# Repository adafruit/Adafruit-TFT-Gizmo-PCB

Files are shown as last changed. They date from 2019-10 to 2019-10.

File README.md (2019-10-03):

## Adafruit Circuit Playground TFT Gizmo - Bolt-on Display + Audio Amplifier PCB

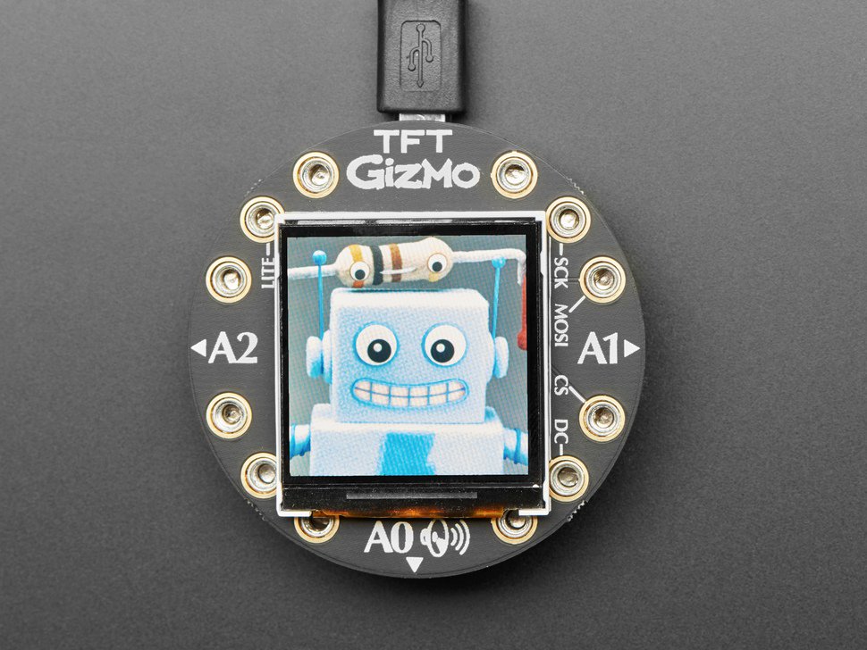
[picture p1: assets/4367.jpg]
<a href="http://www.adafruit.com/products/4367"><br/>
Click here to purchase one from the Adafruit shop</a>

PCB files for the Adafruit Circuit Playground TFT Gizmo - Bolt-on Display + Audio Amplifier. 

Format is EagleCAD schematic and board layout
* https://www.adafruit.com/product/4367

### Description

Extend and expand your Circuit Playground projects with a bolt on TFT Gizmo that lets you add a lovely color display in a sturdy and reliable fashion. This PCB looks just like a round TFT breakout but has permanently affixed M3 standoffs that act as mechanical and electrical connections.

Once attached you'll get a 1.54" 240x240 IPS display with backlight control, two 3-pin STEMMA connectors for attaching NeoPixel strips or servos, and a Class D audio amplifier with a Molex PicoBlade connector that can plug one of our lil speakers.

This is a great companion for our Circuit Playground Express or Bluefruit boards thanks to their fast SPI hardware speeds, and works in Arduino and CircuitPython. You can use it with the Circuit Playground Classic but it won't be very fast, as you have to bitbang the SPI - and the display has a lot of pixels - so it's not recommended.

Comes with a PCB that has pre-soldered standoffs attached, and 12x M3 screws for attachment. Fits all Circuit Playgrounds but like we mentioned earlier, the Express and Bluefruit are recommended.

### License

Adafruit invests time and resources providing this open source design, please support Adafruit and open-source hardware by purchasing products from [Adafruit](https://www.adafruit.com)!

Designed by Limor Fried/Ladyada for Adafruit Industries.

Creative Commons Attribution/Share-Alike, all text above must be included in any redistribution. 
See license.txt for additional details.

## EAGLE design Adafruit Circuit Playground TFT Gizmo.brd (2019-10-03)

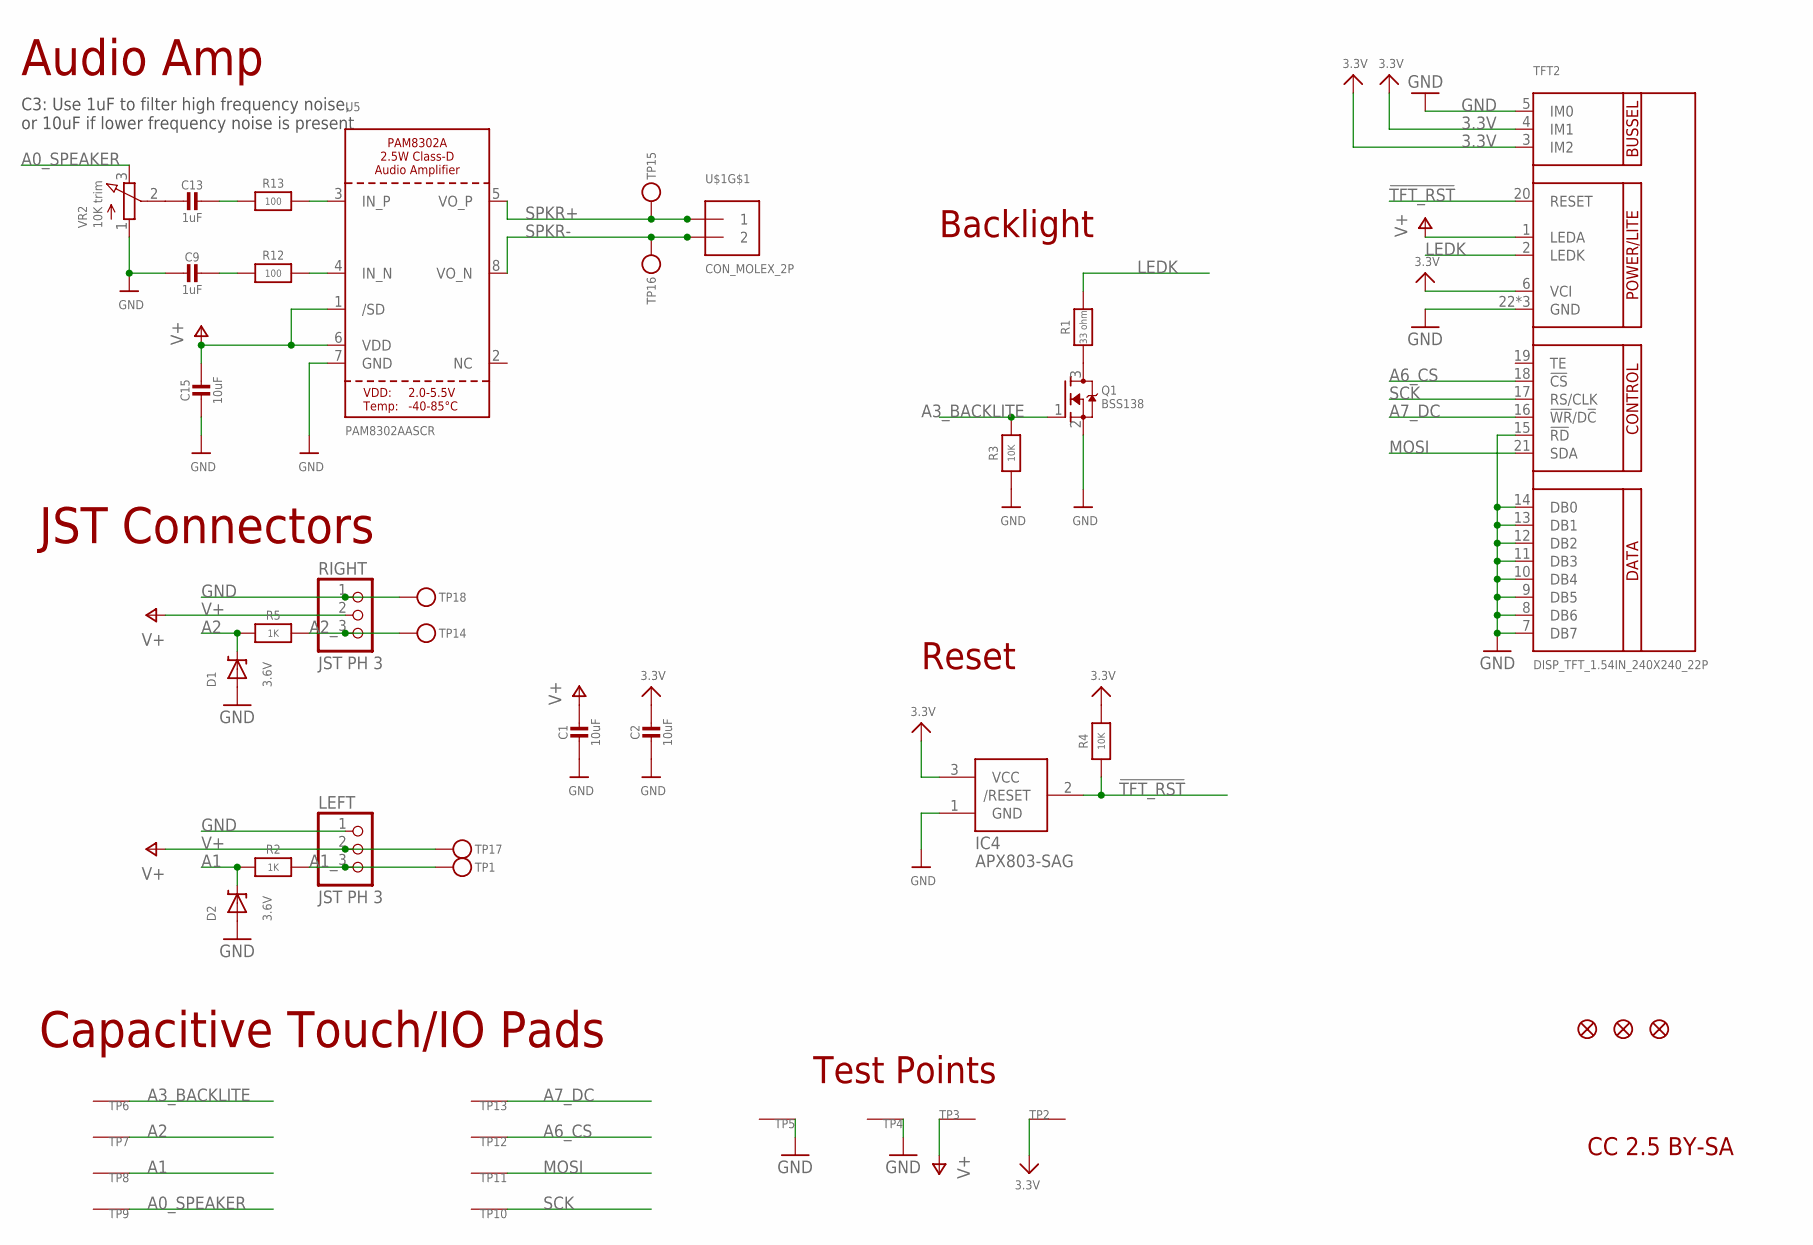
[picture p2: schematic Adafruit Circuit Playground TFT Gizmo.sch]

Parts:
C1, C2, C15: 10uF; 0805-NO
C9, C13: 1uF; 0603-NO
D1, D2: 3.6V; SOD-323
IC4: APX803-SAG; SOT23
LEFT: JST PH 3; JSTPH3
Q1: BSS138; SOT23-WIDE
R1: 33 ohm; 0603-NO
R2, R5: 1K; 0603-NO
R3, R4: 10K; 0603-NO
R12, R13: 100; 0603-NO
RIGHT: JST PH 3; JSTPH3
TFT2: DISP_TFT_1.54IN_240X240_22P; TFT_1.54IN_240X240_22PIN
TP1, TP14, TP15, TP16, TP17, TP18: TESTPOINTROUND1.5MMNO; TESTPOINT_ROUND_1.5MM_NO
TP2, TP3, TP4, TP5, TP6, TP7, TP8, TP9, TP10, TP11, TP12, TP13: SEWTAP_SMTNUTM3; SMT_NUT_3MM
U5: PAM8302AASCR; MSOP8_0.65MM
U$1: CON_MOLEX_2P; 53398-0271
U$2, U$3, U$6: FIDUCIAL_1MM
VR2: 10K trim; TRIMPOT_BOURNS_3303W

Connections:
3.3V: C2.1, IC4.3 (VCC), R4.2, TFT2.3 (IM2), TFT2.4 (IM1), TFT2.6 (VCI), TP2.P$1
!TFT_RST: IC4.2 (/RESET), R4.1, TFT2.20 (RESET)
A0_SPEAKER: TP9.P$1, VR2.3 (E)
A1: D2.C, R2.2, TP8.P$1
A1_: LEFT.3, R2.1, TP1.P$1
A2: D1.C, R5.2, TP7.P$1
A2_: R5.1, RIGHT.3, TP14.P$1
A3_BACKLITE: Q1.1 (G), R3.2, TP6.P$1
A6_CS: TFT2.18 (!CS), TP12.P$1
A7_DC: TFT2.16 (!WR!/D!C), TP13.P$1
GND: C1.2, C2.2, C9.2, C15.2, D1.A, D2.A, IC4.1 (GND), LEFT.1, Q1.2 (S), R3.1, RIGHT.1, TFT2.5 (IM0), TFT2.7 (DB7), TFT2.8 (DB6), TFT2.9 (DB5), TFT2.10 (DB4), TFT2.11 (DB3), TFT2.12 (DB2), TFT2.13 (DB1), TFT2.14 (DB0), TFT2.15 (!RD), TFT2.22 (GND), TFT2.SUPPORT1 (GND), TFT2.SUPPORT2 (GND), TP4.P$1, TP5.P$1, TP18.P$1, U5.7 (GND), VR2.1 (A)
LEDK: R1.2, TFT2.2 (LEDK)
MOSI: TFT2.21 (SDA), TP11.P$1
unnamed: Q1.3 (D), R1.1
unnamed: R12.2, U5.4 (IN_N)
unnamed: R13.2, U5.3 (IN_P)
unnamed: C9.1, R12.1
unnamed: C13.1, R13.1
unnamed: C13.2, VR2.2 (S)
SCK: TFT2.17 (RS/CLK), TP10.P$1
SPKR+: TP15.P$1, U5.5 (VO_P), U$1.1
SPKR-: TP16.P$1, U5.8 (VO_N), U$1.2
V+: C1.1, C15.1, LEFT.2, RIGHT.2, TFT2.1 (LEDA), TP3.P$1, TP17.P$1, U5.1 (/SD), U5.6 (VDD)

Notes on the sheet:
CC 2.5 BY-SA
Capacitive Touch/IO Pads
C3: Use 1uF to filter high frequency noise, or 10uF if lower frequency noise is present
Audio Amp
JST Connectors
Test Points
Reset
Backlight

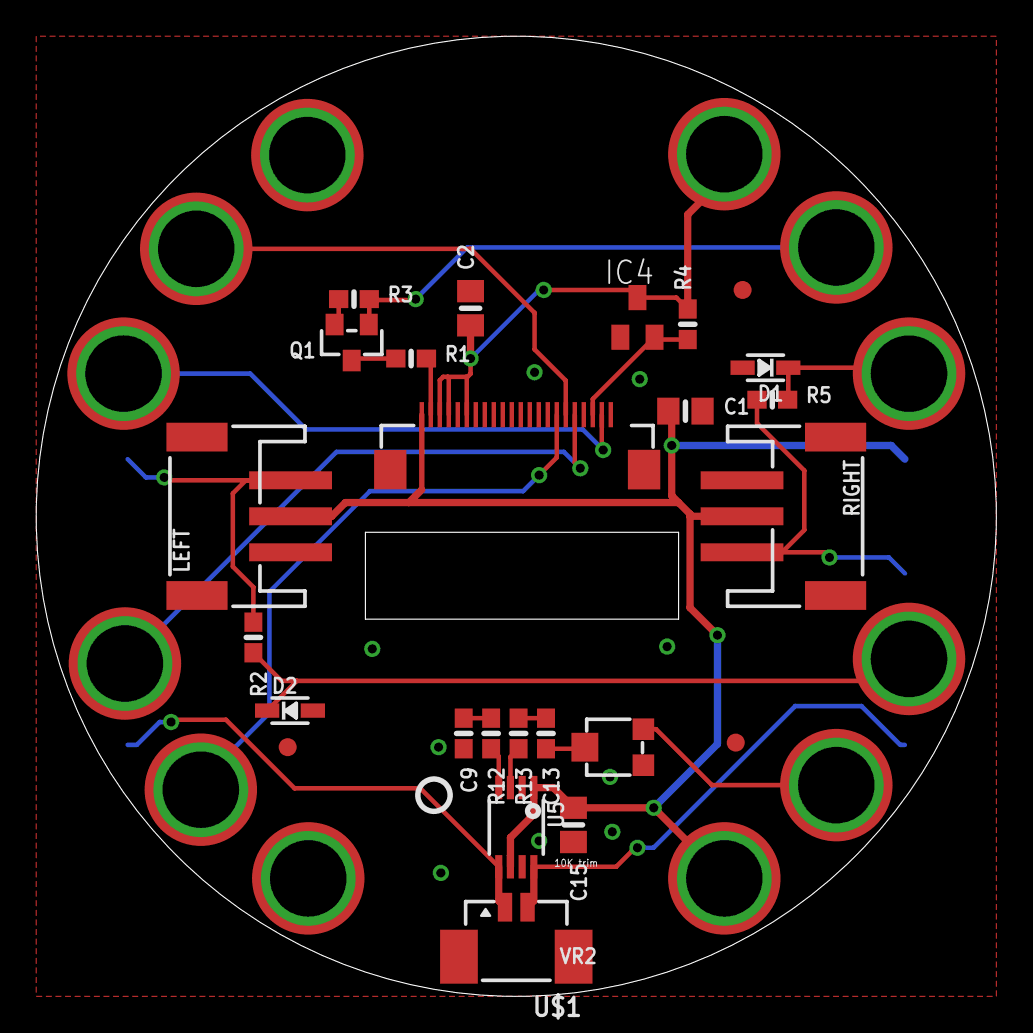
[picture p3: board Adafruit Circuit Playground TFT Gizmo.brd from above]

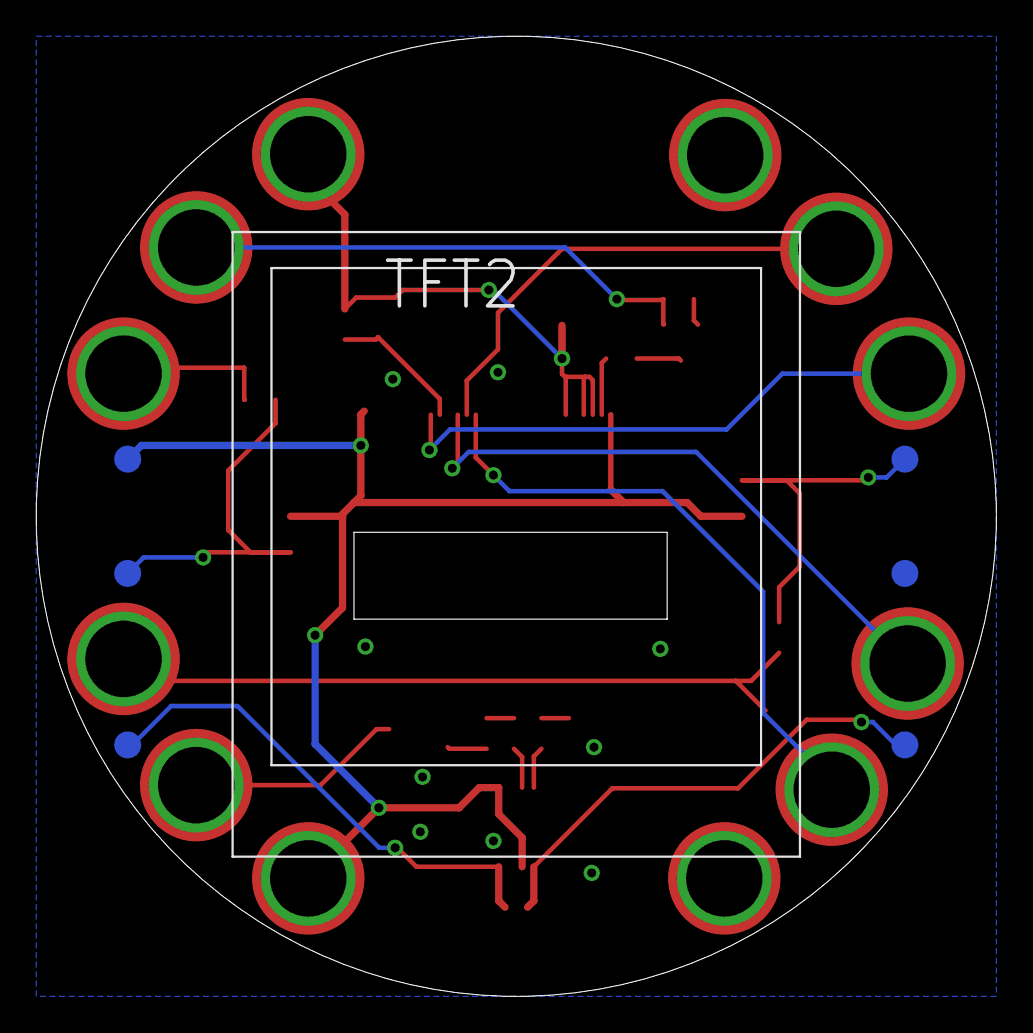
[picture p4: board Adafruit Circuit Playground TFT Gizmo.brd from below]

Board: 2 copper layers, 53.3 x 53.3 mm, 46 parts (8 on the bottom side), 23 nets.

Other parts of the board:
U$7: PCBFEAT-REV-040
U$17: TFTGIZMO_FRONT
U$18: TFTGIZMO_BACK

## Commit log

2019-10-03 Adding board files
    [Adafruit Circuit Playground TFT Gizmo.brd, Adafruit Circuit Playground TFT Gizmo.sch]
2019-10-03 Updated to D1 Revision
    [Adafruit Circuit Playground TFT Gizmo.brd, Adafruit Circuit Playground TFT Gizmo.sch]

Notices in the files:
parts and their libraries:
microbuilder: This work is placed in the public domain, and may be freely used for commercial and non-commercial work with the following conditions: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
